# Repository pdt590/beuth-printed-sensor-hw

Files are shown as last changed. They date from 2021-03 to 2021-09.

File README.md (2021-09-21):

# PrintED

Readout device hardware for PrintED project

- Readout Device

Front                              |  Edge
:---------------------------------:|:--------------------------------------:
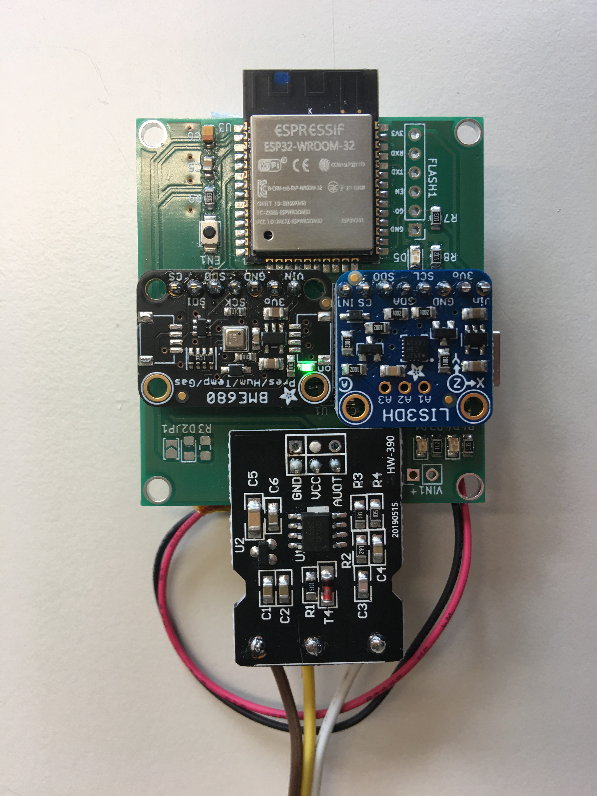
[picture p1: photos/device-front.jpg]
front
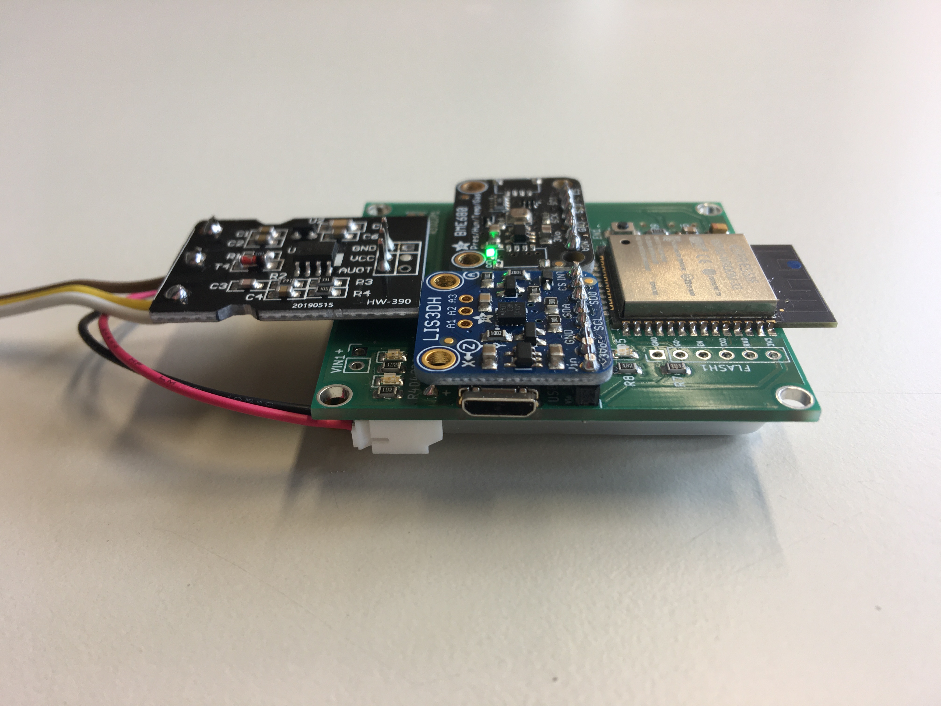
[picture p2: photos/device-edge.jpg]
edge
  | 

- Readout Device with PrintED Sensor

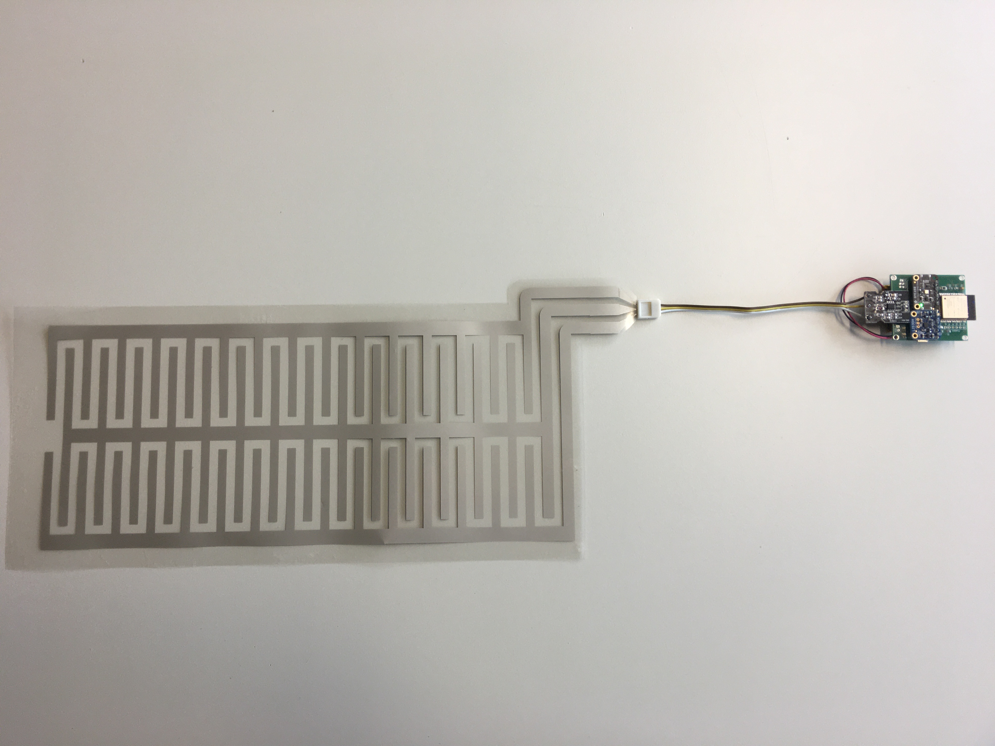
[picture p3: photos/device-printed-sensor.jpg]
sensor


- System Deployment

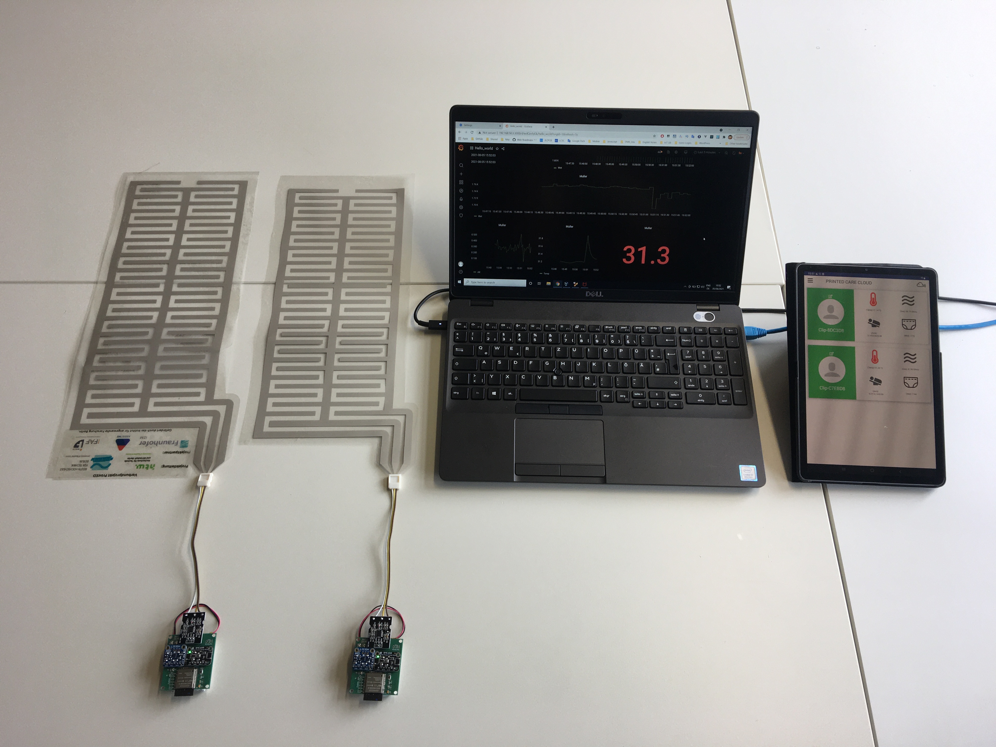
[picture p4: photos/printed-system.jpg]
system


## Compatibility

- [beuth-printed-sensor-fw](https://github.com/pdt590/beuth-printed-sensor-fw)
- [beuth-printed-app](https://github.com/pdt590/beuth-printed-app)
- [beuth-printed-cloud](https://github.com/pdt590/beuth-printed-cloud)

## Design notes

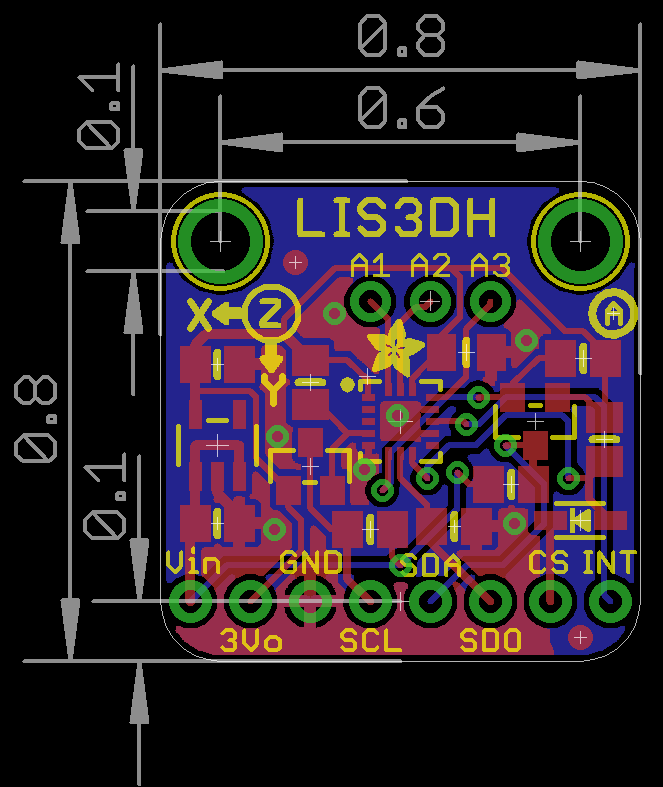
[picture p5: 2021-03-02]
photos/lis3dh.png

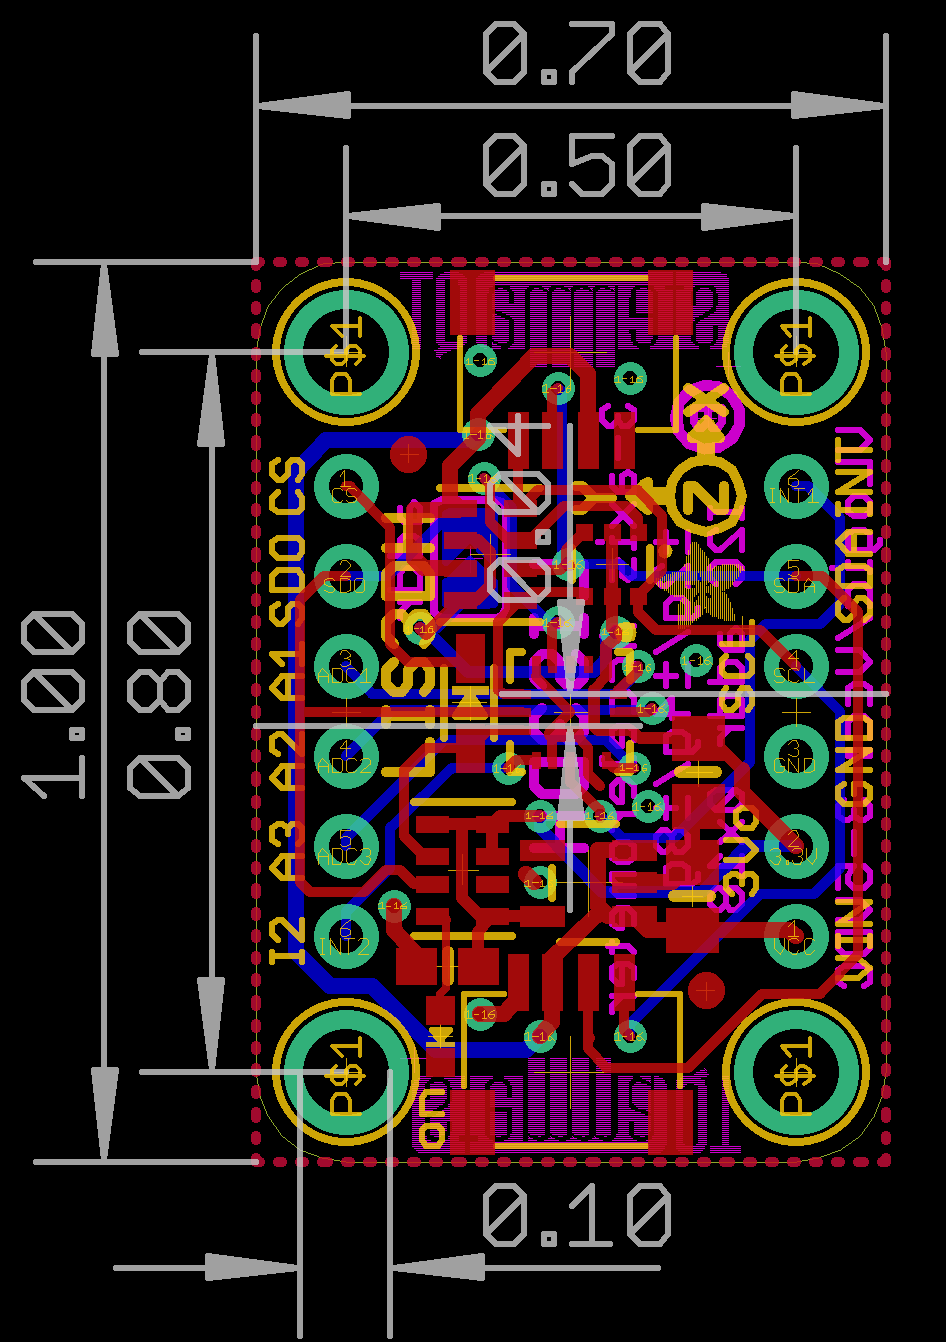
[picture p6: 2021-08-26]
photos/lis3dh-new.png

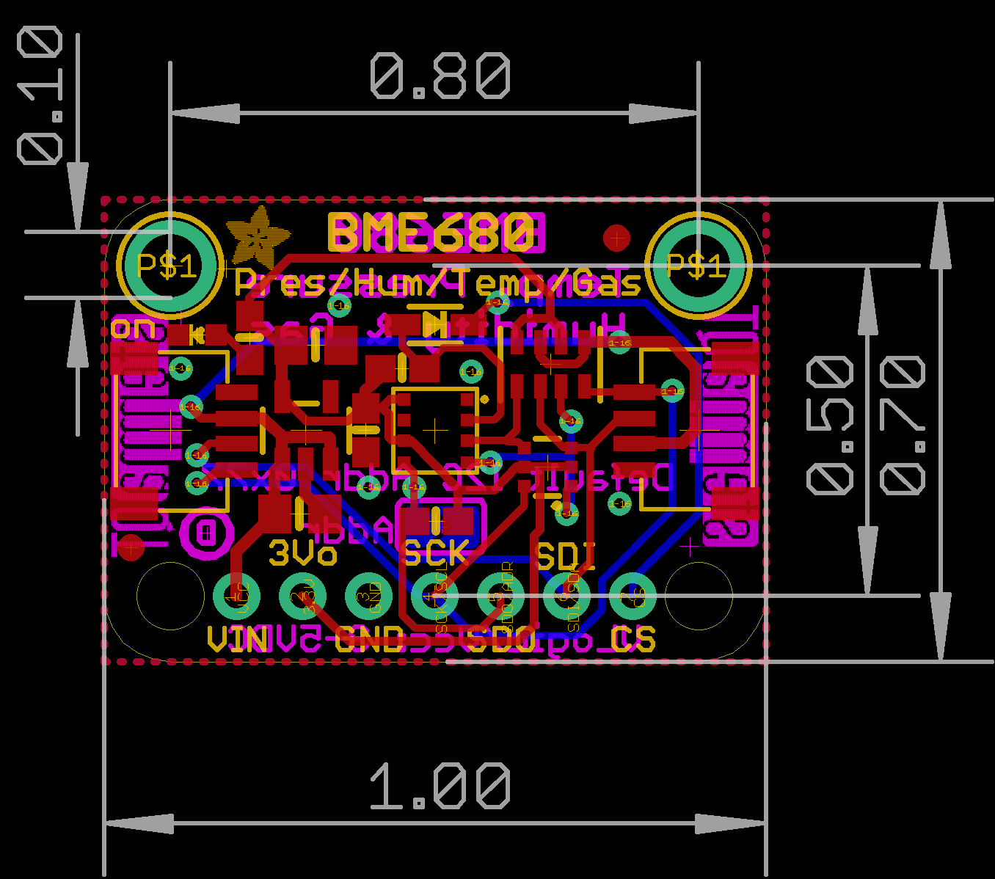
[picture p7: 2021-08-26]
photos/bme680-new.png

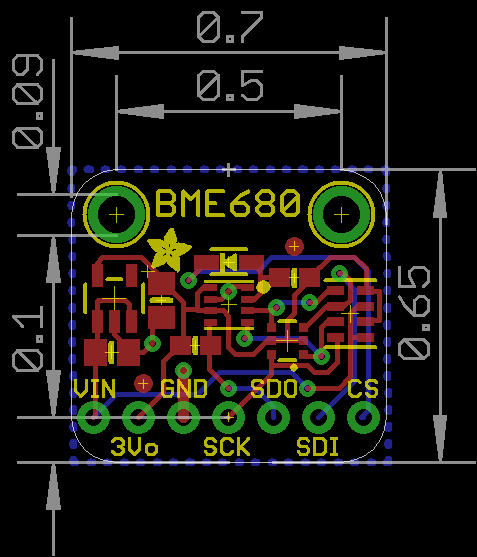
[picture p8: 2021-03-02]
photos/bme680.png

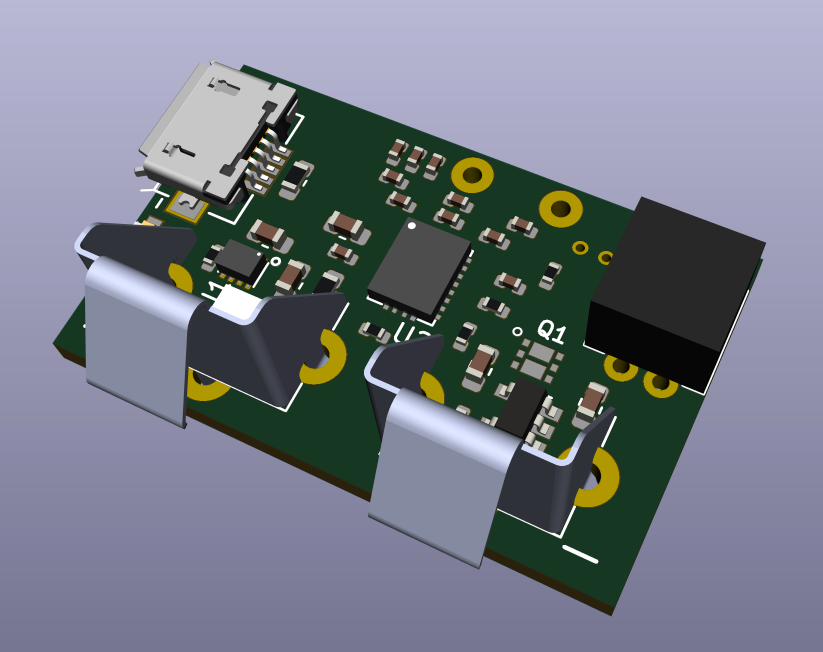
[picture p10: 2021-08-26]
3d/usb-refer.png

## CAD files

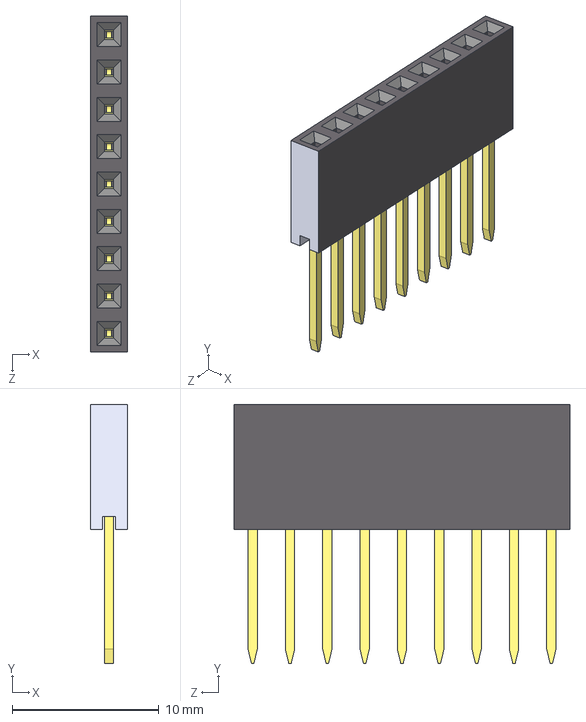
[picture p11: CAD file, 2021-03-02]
3d/pin-header-female-1.snapshot.13/1x9.STEP
2.54 x 17.6 x 22.9 mm

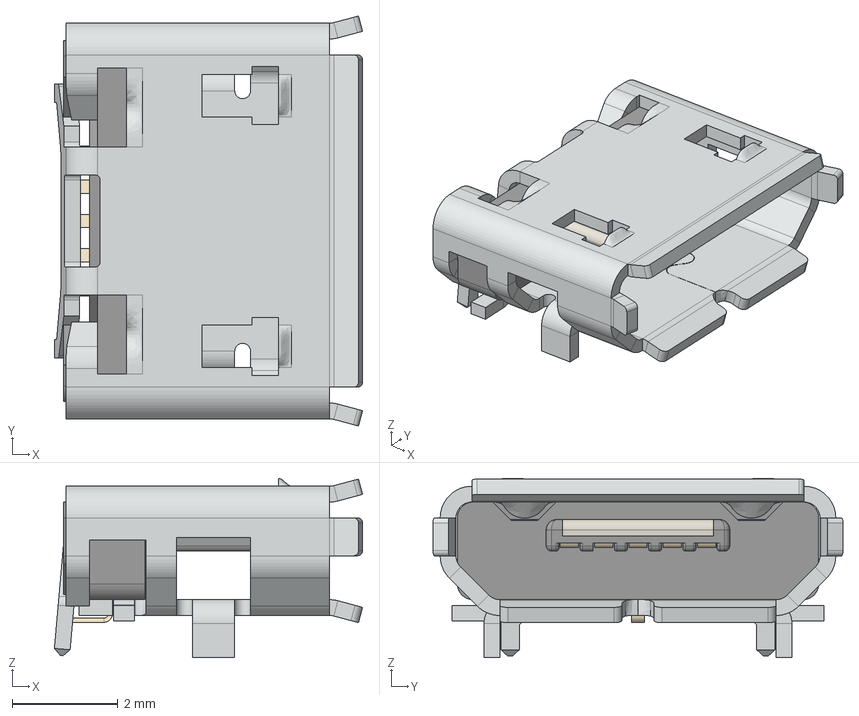
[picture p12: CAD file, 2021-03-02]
3d/usb-micro-b-molex-1013594-1.snapshot.7/micro_usb_connector.stp
5.84 x 7.77 x 3.40 mm
shield
socket_housing
socket_plate
terminal x 5

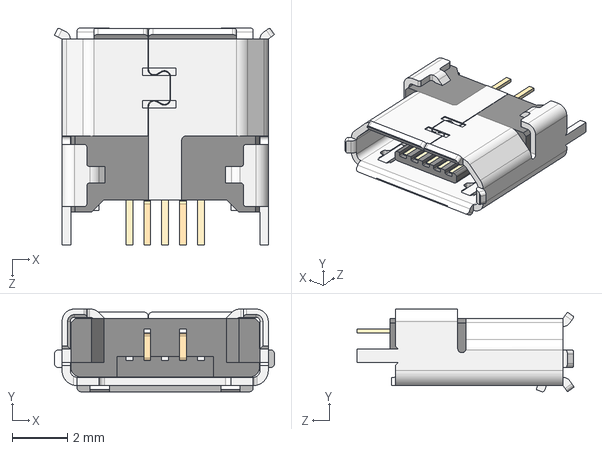
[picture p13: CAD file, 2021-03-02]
3d/User Library-Micro USB B THT vertical.step
8.00 x 3.01 x 7.91 mm

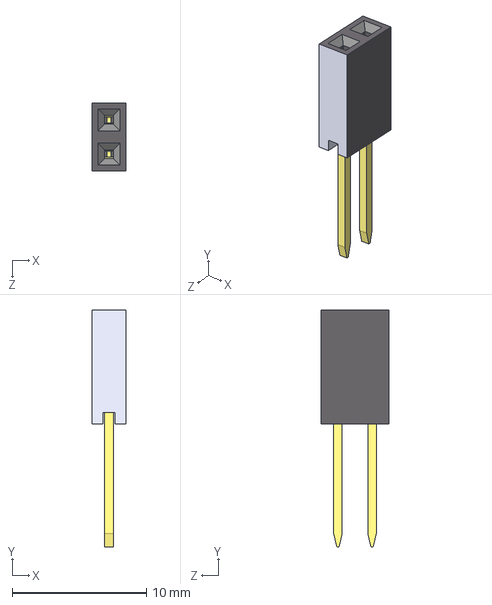
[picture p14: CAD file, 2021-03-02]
3d/pin-header-female-1.snapshot.13/1x2.STEP
2.54 x 17.6 x 5.08 mm

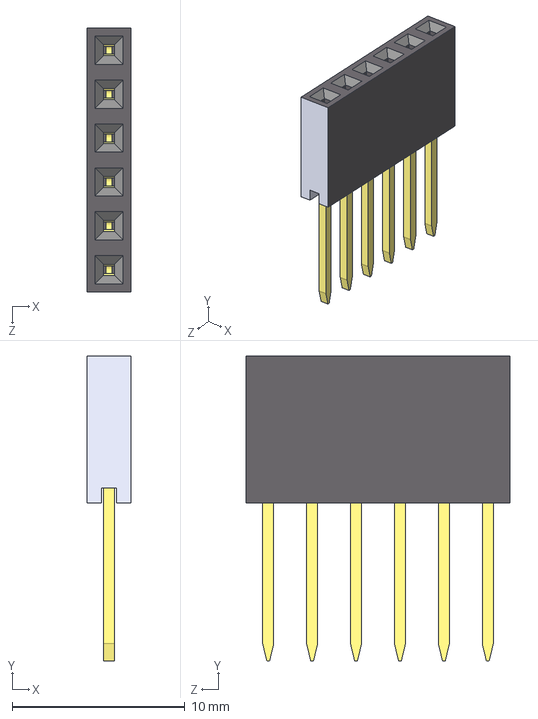
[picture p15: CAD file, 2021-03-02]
3d/pin-header-female-1.snapshot.13/1x6.STEP
2.54 x 17.6 x 15.2 mm

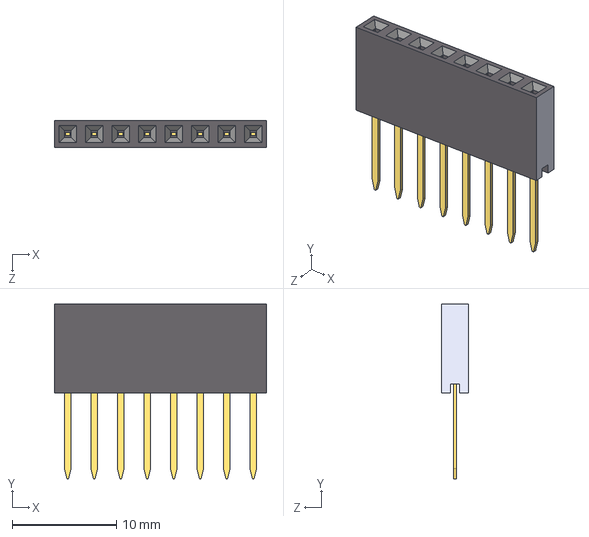
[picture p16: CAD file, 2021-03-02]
3d/pin-header-female-1.snapshot.13/1x8.STEP
20.3 x 16.8 x 2.54 mm

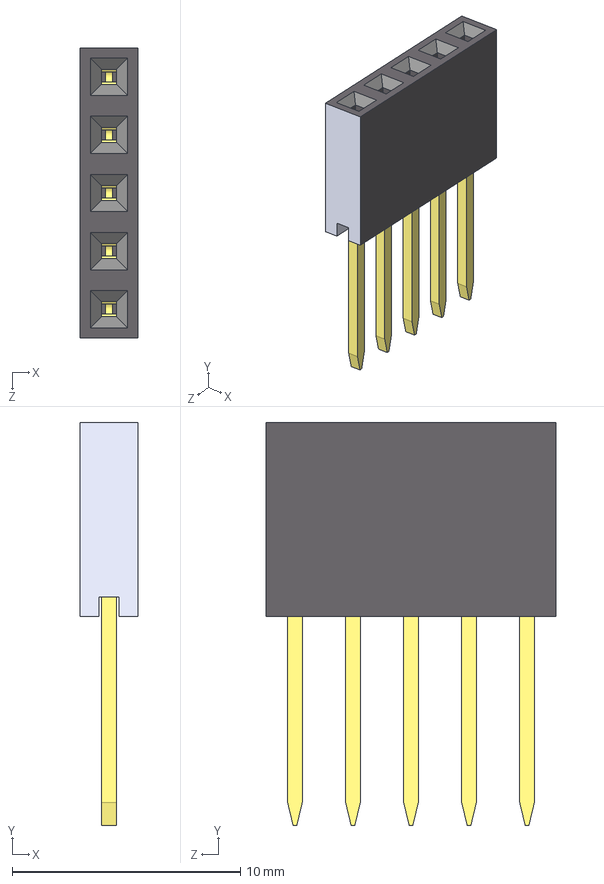
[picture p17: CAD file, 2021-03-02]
3d/pin-header-female-1.snapshot.13/1x5.STEP
2.54 x 17.6 x 12.7 mm

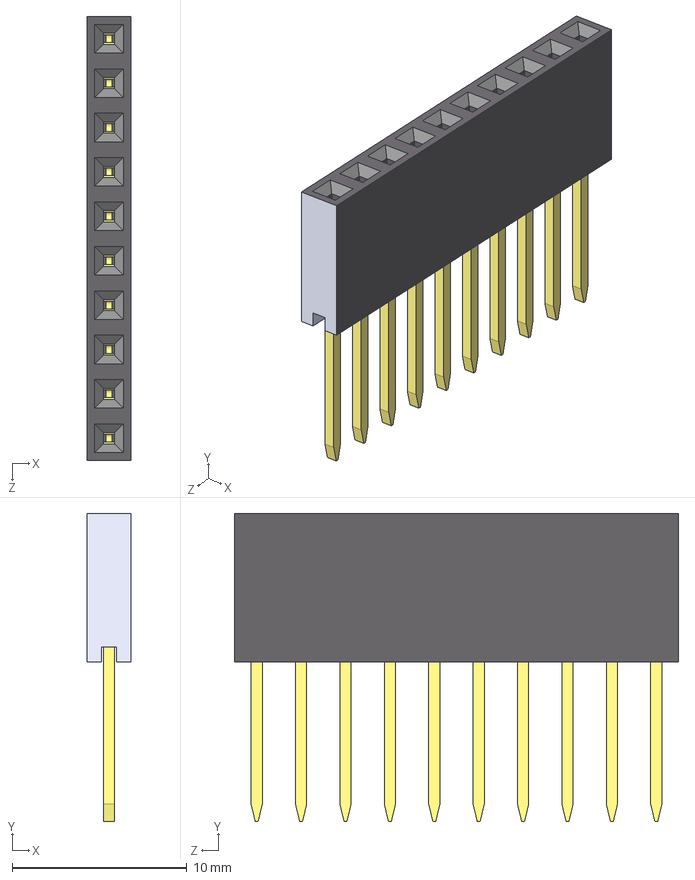
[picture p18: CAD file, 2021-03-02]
3d/pin-header-female-1.snapshot.13/1x10.STEP
2.54 x 17.6 x 25.4 mm

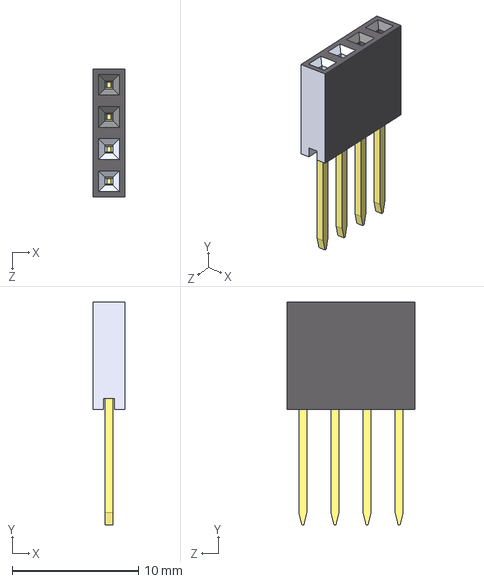
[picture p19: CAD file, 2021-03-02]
3d/pin-header-female-1.snapshot.13/1x4.STEP
2.54 x 17.6 x 10.2 mm

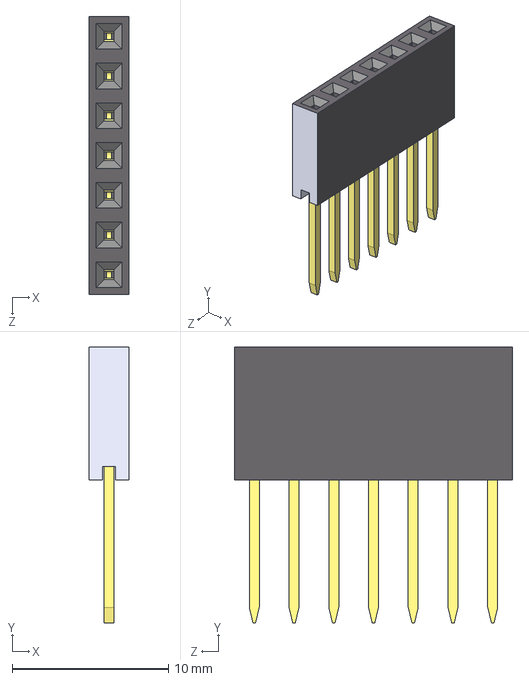
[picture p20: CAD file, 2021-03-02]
3d/pin-header-female-1.snapshot.13/1x7.STEP
2.54 x 17.6 x 17.8 mm

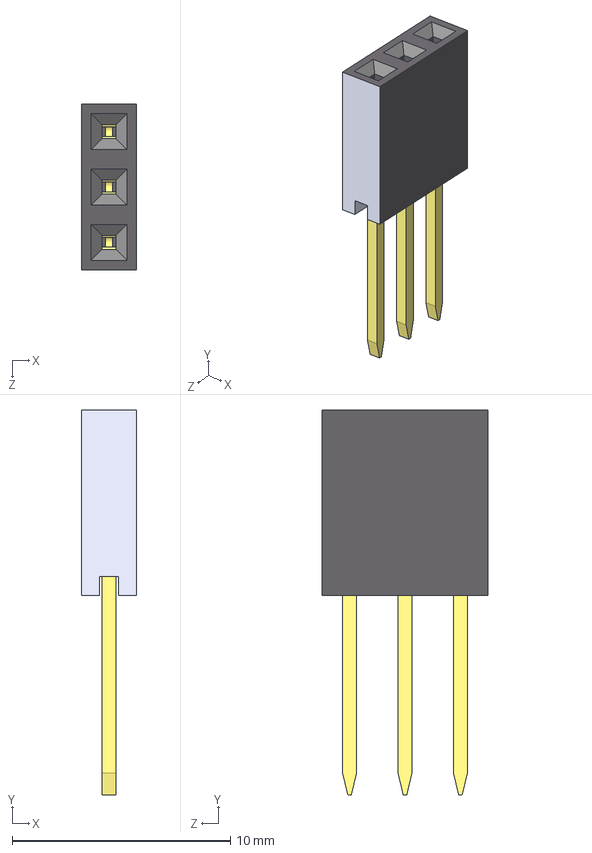
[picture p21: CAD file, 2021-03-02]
3d/pin-header-female-1.snapshot.13/1x3.STEP
2.54 x 17.6 x 7.62 mm

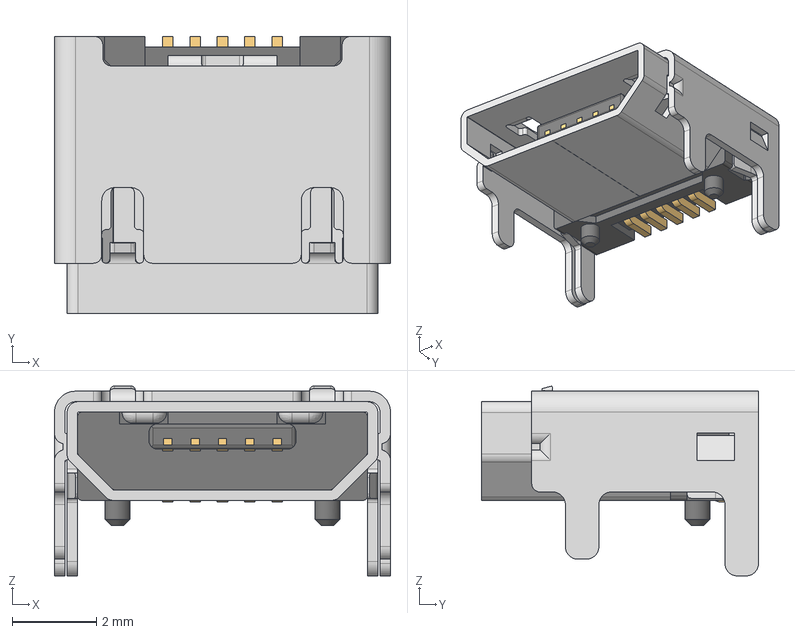
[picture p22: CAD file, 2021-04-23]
3d/usb-wurth-629105150521/629105150521_Download_STP_629105150521_rev1.stp
8.00 x 6.60 x 4.52 mm
629105150521_Pin1 x 4
629105150521_Housing
629105150521_Pin2
629105150521_Shielding
629105150521_Shielding2

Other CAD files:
3d/usb-micro-b-molex-1013594-1.snapshot.7/micro_usb_connector.igs
3d/usb-micro-b-molex-1013594-1.snapshot.7/micro_usb_connector.skp
3d/usb-micro-b-molex-1013594-1.snapshot.7/micro_usb_connector.stl

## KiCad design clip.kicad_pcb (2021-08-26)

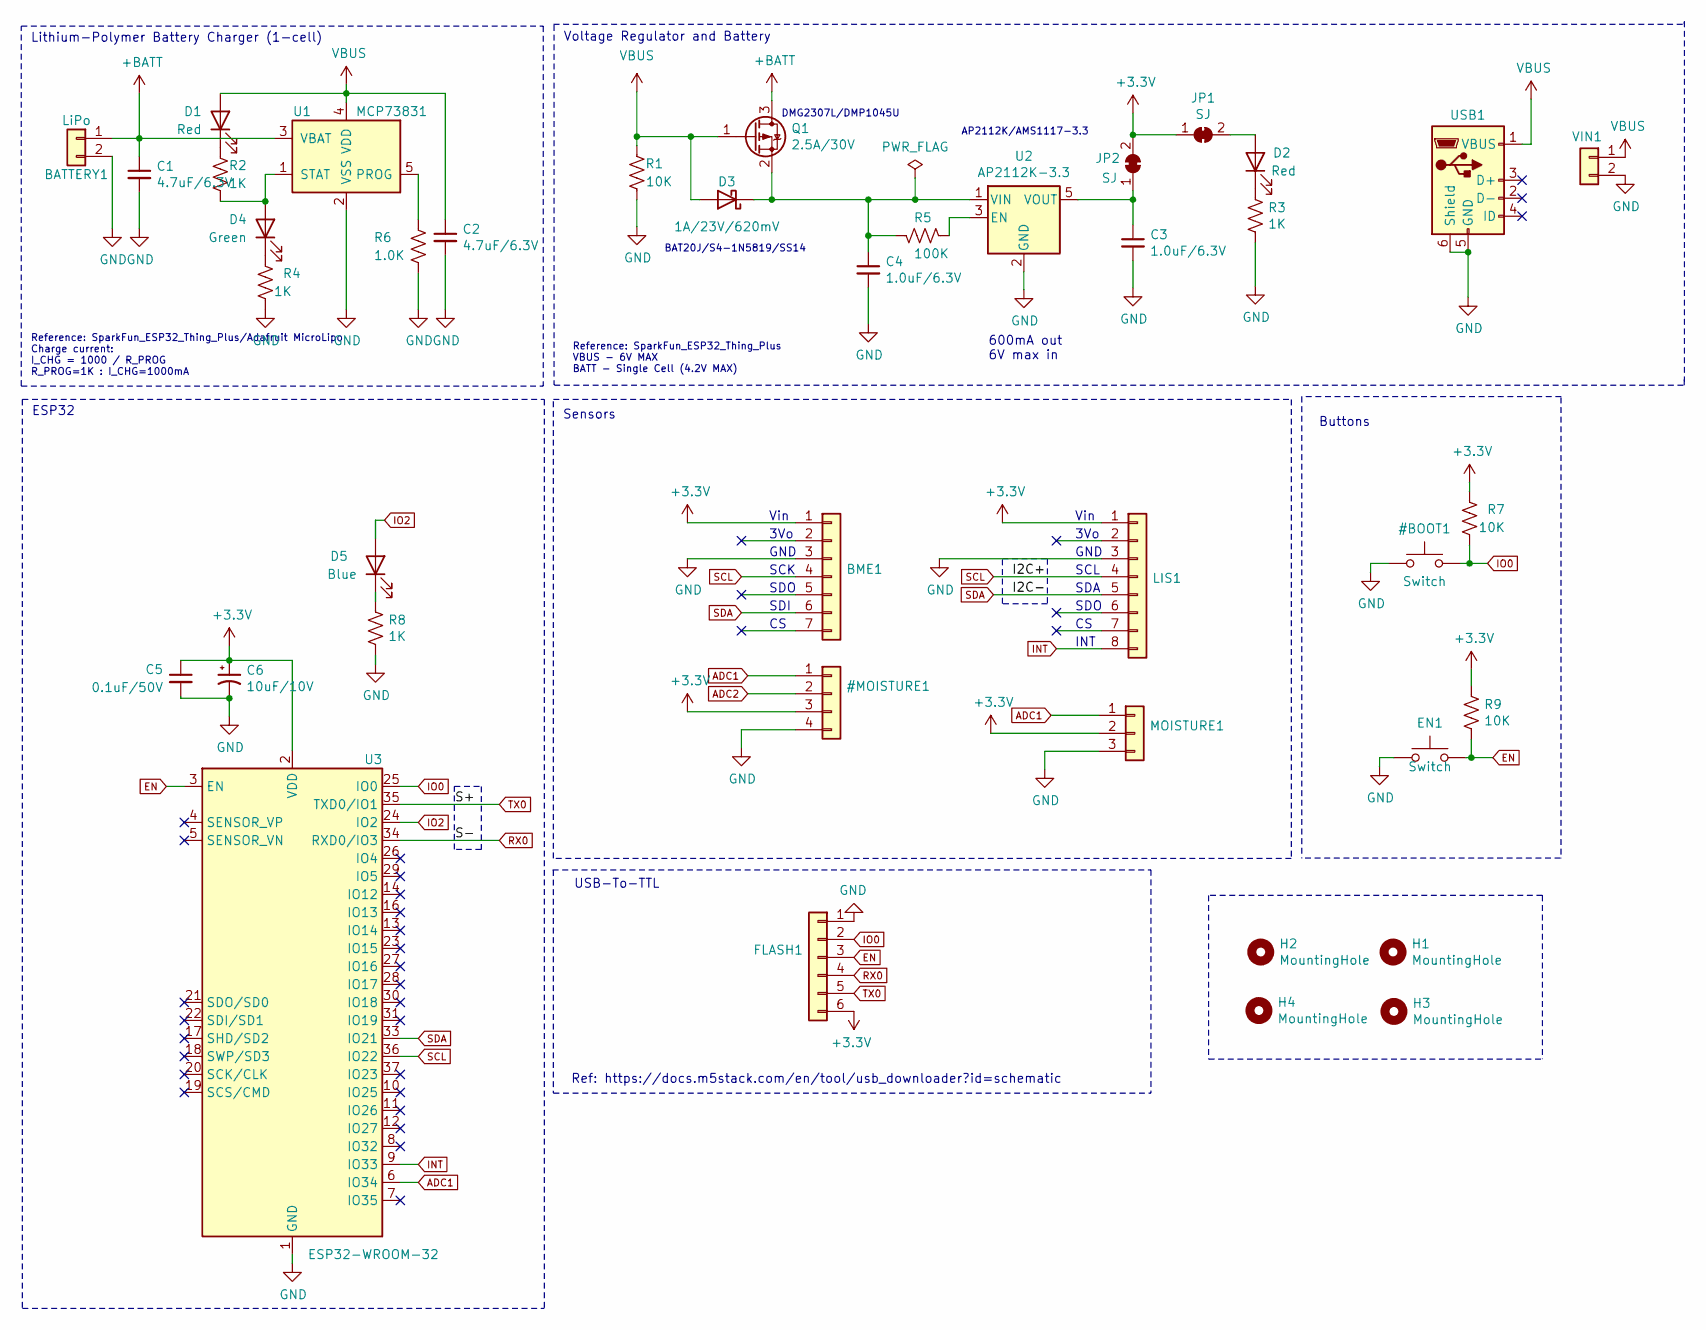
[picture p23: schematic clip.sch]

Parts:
BATTERY1: LiPo; JST_PH_S2B-PH-K_1x02_P2.00mm_Horizontal; Digikey 455-1719-ND
BME1: BME680; PinHeader_1x07_P2.54mm_Vertical; Digikey S7006-ND
C1, C2: 4.7uF/6.3V; C_0805_2012Metric_Pad1.15x1.40mm_HandSolder; Digikey 732-7647-1-ND
C3, C4: 1.0uF/6.3V; C_0805_2012Metric_Pad1.15x1.40mm_HandSolder; Digikey 732-7654-1-ND
C5: 0.1uF/50V; C_0805_2012Metric_Pad1.15x1.40mm_HandSolder; Digikey 732-8080-1-ND
C6: 10uF/10V; C_0805_2012Metric_Pad1.15x1.40mm_HandSolder; Digikey 478-3346-1-ND
D1: Red; LED_0805_2012Metric_Pad1.15x1.40mm_HandSolder; Digikey 732-4984-1-ND
D2: Red; LED_0805_2012Metric_Pad1.15x1.40mm_HandSolder; Digikey 732-4987-1-ND
D3: 1A/23V/620mV; D_SOD-323_HandSoldering; Digikey 497-3381-1-ND
D4: Green; LED_0805_2012Metric_Pad1.15x1.40mm_HandSolder; Digikey 732-4983-1-ND
D5: Blue; LED_0805_2012Metric_Pad1.15x1.40mm_HandSolder; Digikey 732-4982-1-ND
EN1: Switch; SW_SPST_B3U-1000P-B; Digikey SW1020CT-ND
FLASH1: Conn_01x07; PinHeader_1x06_P2.54mm_Vertical; Digikey 732-5323-ND
H1, H2, H3, H4: MountingHole; MountingHole_2.2mm_M2_DIN965_Pad
JP1, JP2: SJ; SolderJumper-2_P1.3mm_Open_TrianglePad1.0x1.5mm; Digikey 732-5328-ND
LIS1: LIS3DH; PinHeader_1x08_P2.54mm_Vertical; Digikey S7006-ND
MOISTURE1: MOISTURE; PinHeader_1x03_P2.54mm_Vertical
Q1: 2.5A/30V; SOT-23_Handsoldering; Digikey DMG2307L-7DICT-ND
R1, R7, R9: 10K; R_0805_2012Metric_Pad1.15x1.40mm_HandSolder; Digikey P10KDACT-ND
R2, R3, R4, R8: 1K; R_0805_2012Metric_Pad1.15x1.40mm_HandSolder; Digikey P1.0KDACT-ND
R5: 100K; R_0805_2012Metric_Pad1.15x1.40mm_HandSolder; Digikey P100KDACT-ND
R6: 1.0K; R_0805_2012Metric_Pad1.15x1.40mm_HandSolder; Digikey P2.0KDACT-ND
U1: MCP73831; SOT-23-5_HandSoldering; Digikey MCP73831T-2ACI/OTCT-ND
U2: AP2112K-3.3; SOT-23-5_HandSoldering; Digikey AP2112K-3.3TRG1DICT-ND
U3: ESP32-WROOM-32; Digikey 1904-1010-1-ND
USB1: USB_B_Micro; USB_Micro-B_Wuerth_629105150521; Digikey 732-5960-1-ND
VIN1: Conn_01x07; PinHeader_1x02_P2.54mm_Vertical; Digikey 732-5323-ND

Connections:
+BATT: BATTERY1.1, C1.1, Q1.3 (D), U1.3 (VBAT)
EN: EN1.2, FLASH1.3, R9.2, U3.3 (EN)
INT: LIS1.8, U3.9 (IO33)
IO2: D5.2 (A), U3.24 (IO2)
unnamed: C3.1, JP2.1 (A), U2.5 (VOUT)
unnamed: C4.1, D3.1 (K), Q1.2 (S), R5.2, U2.1 (VIN)
unnamed: D1.1 (K), R2.2
unnamed: D2.1 (K), R3.1
unnamed: D2.2 (A), JP1.2 (B)
unnamed: D4.1 (K), R4.2
unnamed: D4.2 (A), R2.1, U1.1 (STAT)
unnamed: D5.1 (K), R8.1
unnamed: R5.1, U2.3 (EN)
unnamed: R6.1, U1.5 (PROG)
RX0: FLASH1.4, U3.34 (RXD0/IO3)
SCL: BME1.4, LIS1.4, U3.36 (IO22)
SDA: BME1.6, LIS1.5, U3.33 (IO21)
TX0: FLASH1.5, U3.35 (TXD0/IO1)
VBUS: C2.1, D1.2 (A), D3.2 (A), Q1.1 (G), R1.2, U1.4 (VDD), USB1.1 (VBUS), VIN1.1

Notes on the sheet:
Voltage Regulator and Battery
Lithium-Polymer Battery Charger (1-cell)
ESP32
Buttons
Sensors
AP2112K/AMS1117-3.3
DMG2307L/DMP1045U
BAT20J/S4-1N5819/SS14
600mA out 6V max in
INT
SDO
SDA
SCL
GND
3Vo
Vin
SDI
SCK
GND
Reference: SparkFun_ESP32_Thing_Plus/Adafruit MicroLipo Charge current: I_CHG = 1000 / R_PROG R_PROG=1K : I_CHG=1000mA
Reference: SparkFun_ESP32_Thing_Plus VBUS - 6V MAX BATT - Single Cell (4.2V MAX)
Ref: https://docs.m5stack.com/en/tool/usb_downloader?id=schematic
USB-To-TTL

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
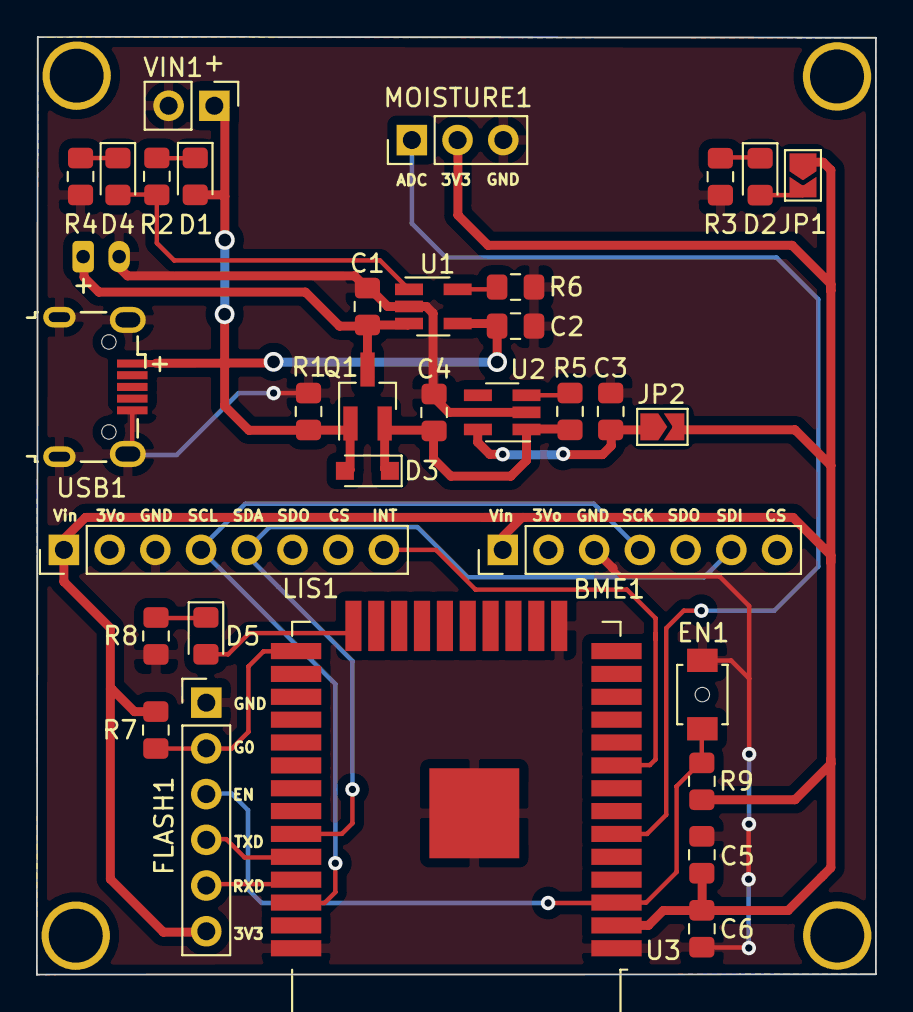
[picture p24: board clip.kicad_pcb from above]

Board: 2 copper layers, 46.6 x 52.1 mm, 38 parts (1 on the bottom side), 23 nets.

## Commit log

2021-01-21 Rename project
    [clip.kicad_pcb, clip.sch, clip_20200407.kicad_pcb]
2021-03-02 Update design
    [1x10.STEP, 1x2.STEP, 1x3.STEP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]
2021-03-31 Add Moisture Sensor Header
    [clip.sch]
2021-04-23 Refactor design
    [629105150521_Download_STP_629105150521_rev1.stp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]
2021-06-30 Refactor files
    [clip-20210603.kicad_pcb, clip-20210611.kicad_pcb, clip-20210614.kicad_pcb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]
2021-08-26 Bump design
    [20210630_clip.kicad_pcb, 20210701_clip.kicad_pcb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]
